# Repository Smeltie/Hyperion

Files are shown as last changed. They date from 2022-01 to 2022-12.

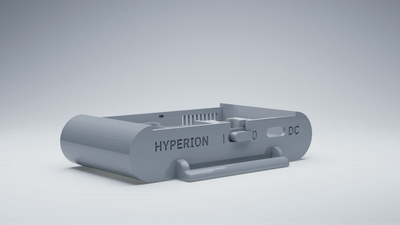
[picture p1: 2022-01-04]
Docs/Case_Lid_Install.gif

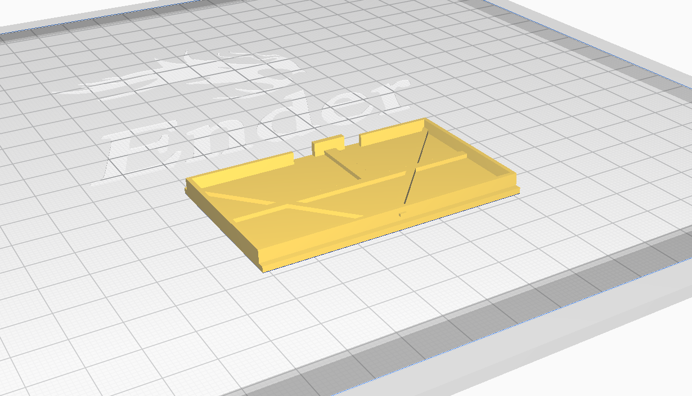
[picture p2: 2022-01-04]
Docs/cura_lid.png

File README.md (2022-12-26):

Imgur <br>

# Hyperion case for DIY SlimeVR!

The Hyperion is one of the smallest and slimmest cases to date for your DIY SlimeVR Trackers. <br>
With its completely tool-less design and tolerances fine tuned specifically for FDM 3D Printers, the Hyperion is both easy to print and assemble! Every part is carefully thought out and clicks together with a satisfying snap, while offering support for various Battery sizes, switches and components.

case

## Index
- [Components](#Components)
- [Compatibility](#Compatibility)
- [Versions](#Versions)
- [Printing](#Printing)
- [Assembly](#Assembly)
- [Links](#Links)
- [Contributors](#Contributors)
- [Contact](#Contact)
- [License (MIT)](#License)

## Components

For the Hyperion you will need the following components:

- [TP4056](https://www.aliexpress.com/item/32649780468.html)
- [Wemos D1 Mini](https://www.aliexpress.com/wholesale?SearchText=D1+mini)
- [40mm straps](https://www.aliexpress.com/item/1005002350231996.html)
- [IMU](https://docs.slimevr.dev/components-guide.html) (*BNO08x chips are currently in a pretty bad shortage*)
    - [MPU6050](https://www.aliexpress.com/wholesale?SearchText=MPU6050)  
    - [BNO08x](https://docs.slimevr.dev/components-guide.html)
- [Switch](https://docs.slimevr.dev/components-guide.html) (*SS22F32 is what the docs suggest, SS12D00G3 is smaller and looks better for this case*)
    - [SS12D00G3](https://www.aliexpress.com/wholesale?SearchText=SS12D00G3)
    - [SS22F32](https://www.aliexpress.com/wholesale?SearchText=SS22F32)
- [Battery](https://docs.slimevr.dev/components-guide.html) (*804040 is what the docs suggest, 503759 is smaller and usually higher capacity*)
    - [804040](https://www.aliexpress.com/wholesale?SearchText=804040)
    - [503759](https://www.aliexpress.com/wholesale?SearchText=503759)

You can also order these parts elsewhere through sites like Amazon with a higher markup which may arrive much faster for a higher cost.

*The straps from the SlimeVR docs are only 25mm wide, while the Hyperion is designed to fit up to 40mm straps for extra stability.*
*Be aware that there are different versions of the TP4056 which are smaller and have less soldering pads, avoid these.*  
*The Micro-USB version of the TP4056 does work but isn't recommended.*

## Compatibility

The Hyperion case offers compatibility for various battery types, for example the 503759 supports any battery that is equal to or smaller than 5x37x59mm.  
Please keep in mind your battery size when planning a build, in this example if you are not using a 503759 or 804040 but your battery is smaller it will still work with this design.  
Be aware that if you use a smaller battery you may have to fill up the space a little bit to prevent the battery from sliding around, while a 503450 would fit just fine.  
  
Hyperion also supports various switch types.  
The case was originally designed to fit the smaller SS12D00G3 switches, but now also supports the SS22F32 (SS12F32 also works).

## Versions

There are a lot of different .STL files included in this project, as the Hyperion supports multiple Battery sizes and separate AUX/extension versions of each case and lid.  
The names of the files indicate what the parts are for and which features they incorporate.  
To clarify some of the terminology, the file name may have a reference to the following:

- *AUX*: This part has an opening for a ribbon/JST cable to an Extension.  
- *BNO08x*: This means the part is meant for BNO08x or MPU 9250/6500 chips
- *BMI160*: This means the part is meant for BMI160 chips
- *503759*: This means the part is meant for batteries that are 5x37x59mm (based on that batteries sizing).
- *SS22F32*: This indicates the part was designed for the switches mentioned in the docs.
- *Slime*: This part has the SlimeVR logo on it, mostly for the lid.
- *Blank*: This part has no print or logo on it, mostly for the lid.

### So which parts do i need?
Of course this is totally dependent on the battery and switch you chose, however you will have to print at least 4 components per tracker, which are:

- Case
- Tray
- Lid
- Switch (*if you opted for the SS12D00G3*)

So for example, you bought a 503739 (or smaller) battery, you would need the following:

- *Case_503759.stl*<br>
- *Tray_503759.stl*<br>
- *Lid_503759.stl*<br>

*BEWARE! if you bought SS22F32 switches, make sure that the part name contains "SS22F32"*

#### If you want to have a tracker that uses an AUX/Extension module
You would need the following:

- *Case_503759_AUX.stl*
- *Lid_503759_AUX.stl*

*The tray is not dependent on the AUX/Extension feature.*

## Printing
It is heavily suggested to print these components on an FDM (Filament based) 3D printer such as the Ender 3 or similar, as all the tolerances have been adjusted to accommodate a wide variety of FDM printers.
Personally I printed my parts on a slightly modified Ender3 V2 using E-Sun PLA+ (gray) with a stock 0.4mm nozzle.

In terms of the printing itself, these parts don't need any support.
Orientation wise the case, tray and switch can be printed as is.
The lid you might want to turn 180 degrees so the flat side is against the bed:

Imgur

#### The Switch
The switch is a little small and harder to print, however it is doable with the right settings:

- *Bed Temperature* - 70c.
- *Initial layer speed* - 10mm/s.
- *Printing speed* - 20mm/s.
- *Infill* - 0%.
- *Layer height* - 0.08mm.
- *Location on the buildplate* - Close to the front or back not in the middle.
- *Build plate adhesion* - Brim.

Imgur

*These settings worked well for me, but your printer may need some slight adjustment. Layer height especially may be challenging for some printers.*
*Take your time and take it slow, I've printed more than a handfull now.*
*Don't print in the middle because on many printers that's a low spot, and this would hinder the adhesion needed to keep this little part stuck down.*

## Assembly

output 

Assembly is rather straight forward however there are some slight things to look out for.
You may have to slightly sand the sides of the tray depending on your printers tolerances, not all printers are created equal. Ideally you will not need to sand anything but it's the easiest solution if any part seems too tight.
It is normal for the tray to snap into place a little bit, it's friction fit.

I suggest soldering things out of the case and using the case/tray as a reference towards wire length, you want to keep your wires rather short like this:

Imgur 

Excess wire length may cause issues with the fit, however there should be more than enough space for wires in the case. You don't have to make them extremely short just keep it manageable.

#### The Switch
After printing the switch the bottom layer of the hole might be a little too tight due to elephant's foot or squish.
In this case you can take a hobby knife or similar and slightly open that first layer up a little bit.

#### The Lid
To install the lid it is best practice to place the lid on the case at an angle with the back side first (vents) so that the notches align. Then lower the front and snap it shut.
To remove the lid again place a fingernail or a pry tool between the lid and the power switch and pry upwards, the lid should snap open.

The lid

#### The Strap
The strap is meant to be run underneath the tracker, otherwise the powerswitch will be obstructed.

## Links
Here are some useful and fun resources:
- [The Docs (SlimeVR Documentation)](https://docs.slimevr.dev/)
- [Github Repository SlimeVR](https://github.com/SlimeVR/)
- [Github Repository Hyperion](https://github.com/Smeltie/Hyperion)
- [Thingiverse Hyperion](https://www.thingiverse.com/thing:5186756)
- [Cults3D Hyperion](https://cults3d.com/en/3d-model/gadget/hyperion-case-for-diy-slimevr)
- [CGTraders Hyperion](https://www.cgtrader.com/free-3d-print-models/hobby-diy/electronics/hyperion-case-for-diy-slimevr)
- [SmeltieVR YouTube](https://www.youtube.com/channel/UC4MEm3i0WxIGPyM8YBV9SSQ)
- [SlimeVR Discord](https://discord.gg/SlimeVR)

## Contributors
I want to put out a sincere thank you to all the people that have helped and tested/measured out various items for this project.  
Thank you: Pjesek, Dinnerbone, Don, Sythe, CalliePepper, Lemming and SuchMeme.

## Contact
If you experience any problems with your Hyperion or have any questions/suggestions?
Feel free to reach out through either Discord I'm [@Smeltie#1999](https://discord.gg/SlimeVR) on the official [SlimeVR Discord server](https://discord.gg/SlimeVR).
You can also shoot me an email: [SmeltieVR@gmail.com](mailto:smeltievr@gmail.com)
If you want to help out with the project or have/want to make a version for a different set of hardware you're more than welcome to send it over or do a merge request!

## License
This project is licensed under the MIT license.

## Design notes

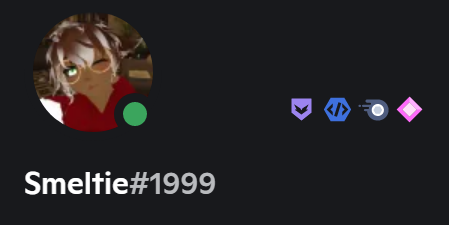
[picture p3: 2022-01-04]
Docs/profile.png

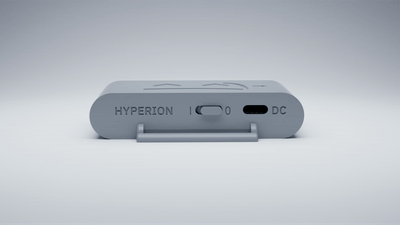
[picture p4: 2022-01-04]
Docs/Case_360.gif

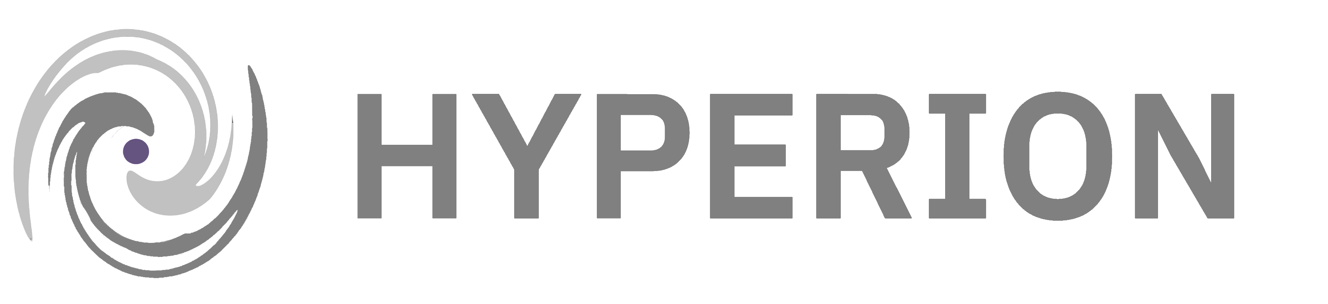
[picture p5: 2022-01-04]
Docs/HYPERION.png

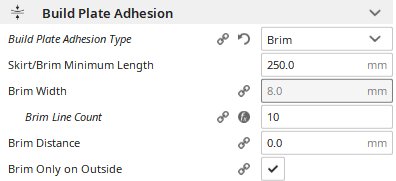
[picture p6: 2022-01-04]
Docs/cura_brim.png

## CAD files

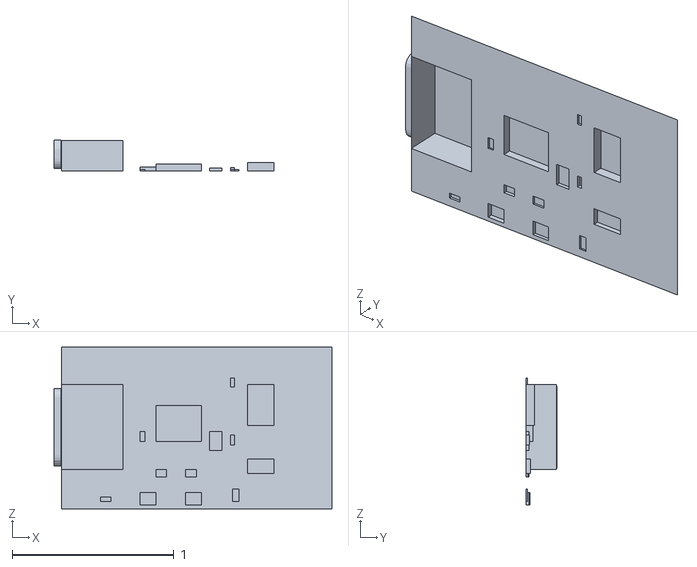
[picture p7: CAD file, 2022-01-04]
3D Models/tp4056.obj
1.72 x 0.193 x 1.00

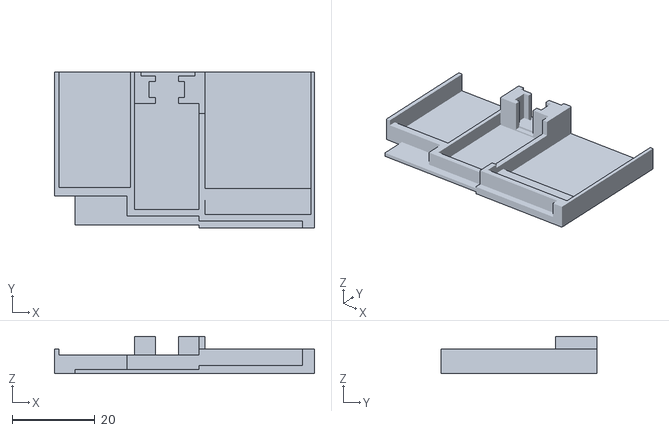
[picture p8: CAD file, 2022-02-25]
STL Files/503759/Tray_503759_BNO08x.stl
62.9 x 37.8 x 9.00

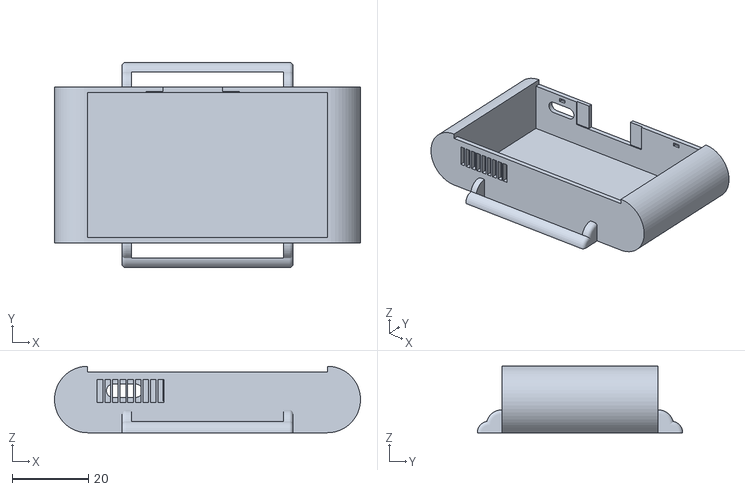
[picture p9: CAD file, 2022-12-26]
STL Files/503759_SS22F32/Case_503759_SS22F32_Switch_Inside.stl
80.5 x 54.0 x 17.5

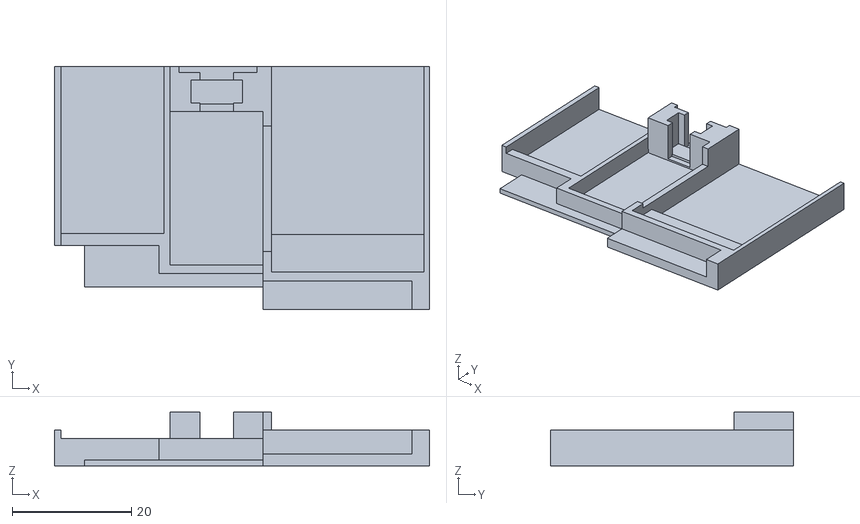
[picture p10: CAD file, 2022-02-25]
STL Files/804040/Tray_804040_BNO08x.stl
62.9 x 40.8 x 9.00

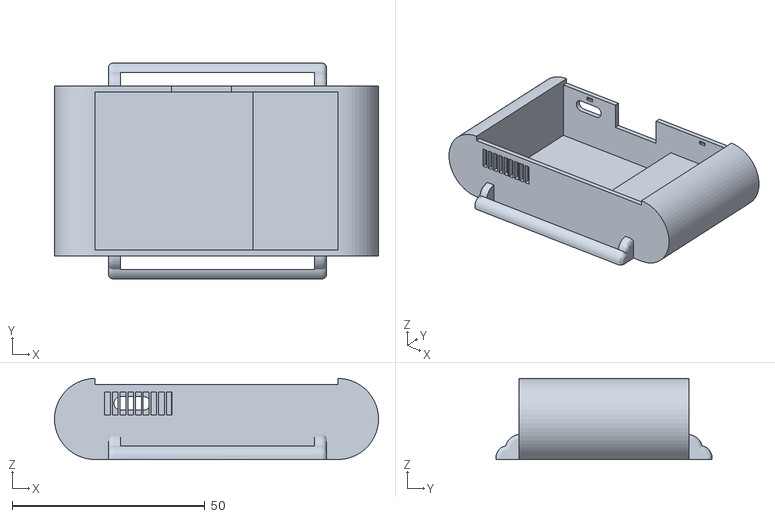
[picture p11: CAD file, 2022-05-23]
STL Files/804040_SS22F32/Case_804040_SS22F32_50mm_Strap.stl
84.0 x 56.0 x 21.0

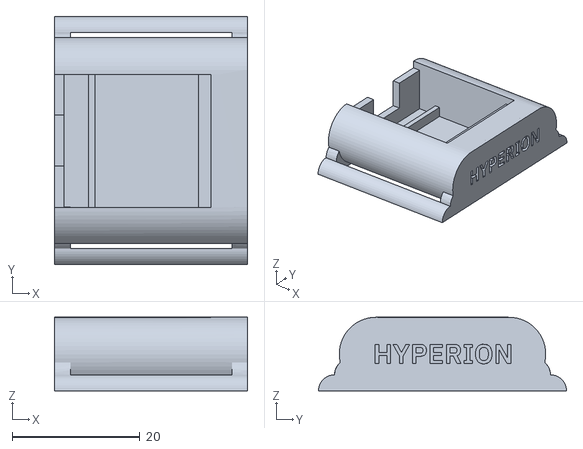
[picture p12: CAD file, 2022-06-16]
STL Files/AUX_Housing_25mm_Strap.stl
30.2 x 38.8 x 11.5

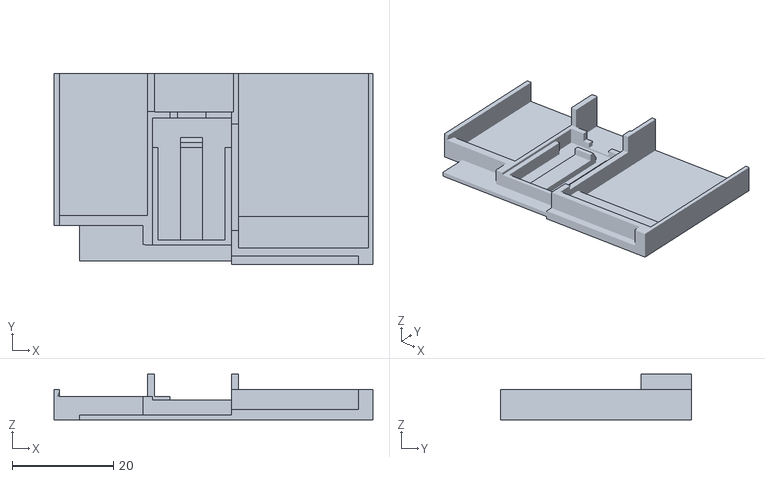
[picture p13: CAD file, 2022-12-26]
Untested/503759_SS22F32/Tray_503759_BMI160_SS22F32.stl
62.9 x 37.8 x 9.00

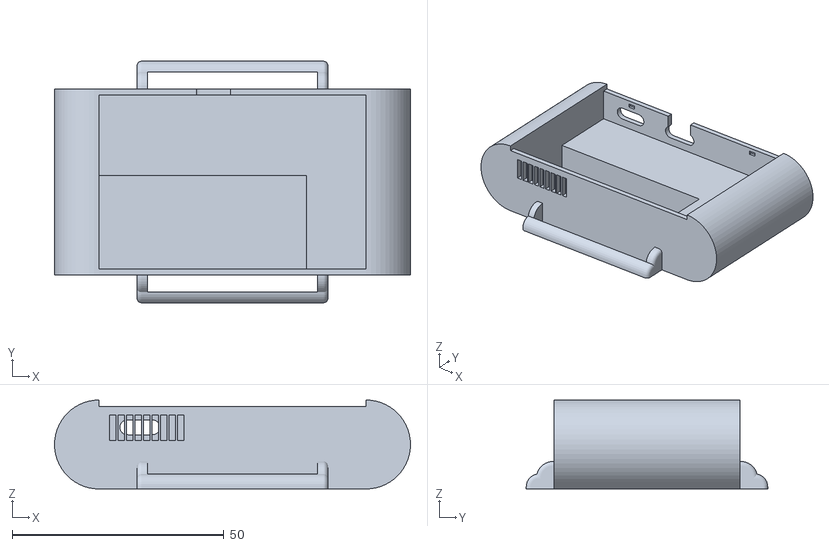
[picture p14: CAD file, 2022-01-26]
Untested/802048/Case_802048.stl
84.0 x 57.0 x 21.0

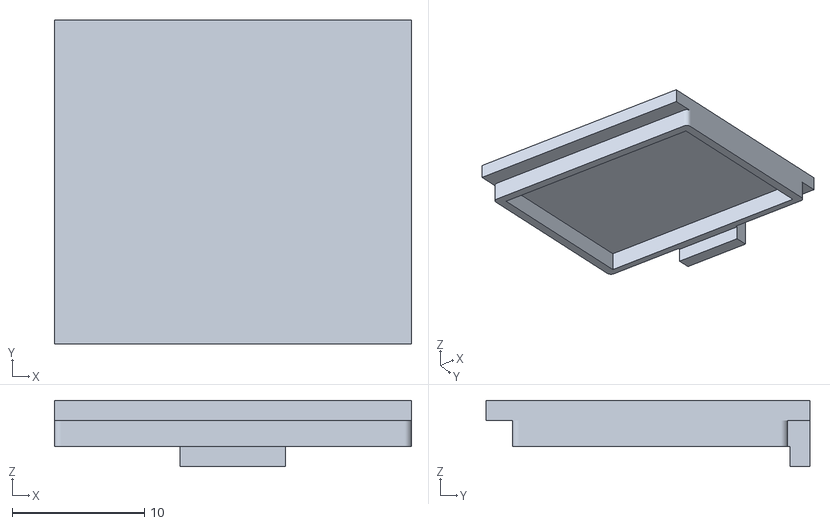
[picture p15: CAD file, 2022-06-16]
Untested/AUX_housing_lid_BNO08x_wide.stl
27.0 x 24.5 x 5.00

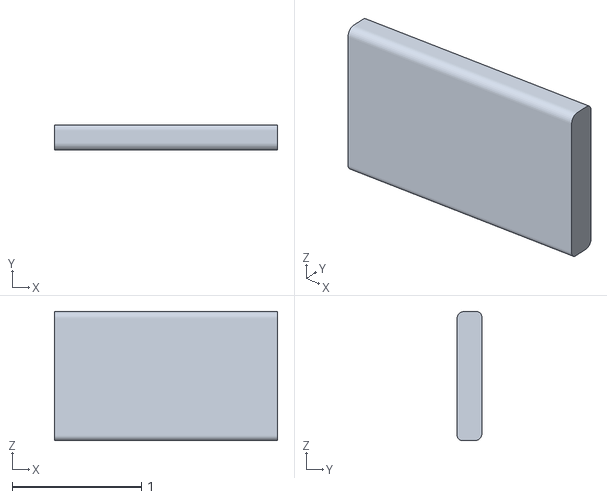
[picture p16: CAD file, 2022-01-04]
3D Models/battery.obj
1.73 x 0.192 x 1.00

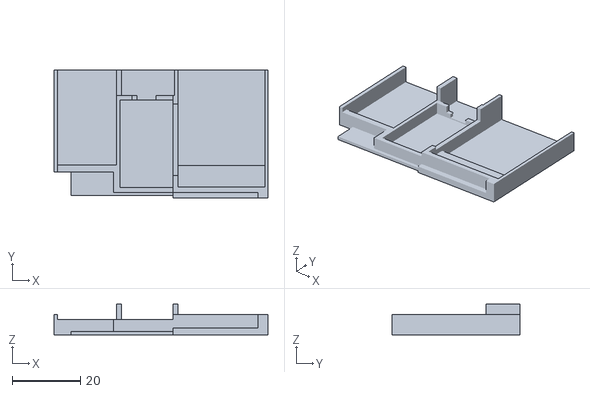
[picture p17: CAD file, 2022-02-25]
STL Files/503759_SS22F32/Tray_503759_BNO08x_SS22F32.stl
62.9 x 37.8 x 9.00

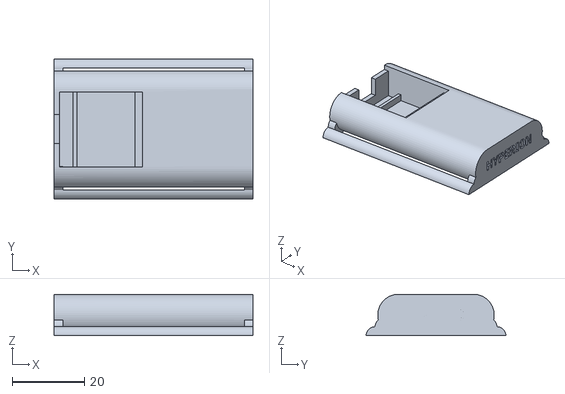
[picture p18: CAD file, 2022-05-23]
STL Files/AUX_Housing_50mm_Strap.stl
55.2 x 38.8 x 11.5

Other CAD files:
Untested/903052/Case_903052.stl
STL Files/503759/Tray_503759.stl
STL Files/804040/Tray_804040.stl
STL Files/804040_SS22F32/Case_804040_SS22F32_AUX_50mm_Strap.stl
Untested/802048/Case_802048_AUX.stl
Untested/903052/Case_903052_SS22F32.stl
3D Models/WemosD1.obj
3D Models/pcb.obj
3D Models/switch.obj
STL Files/503759/Case_503759.stl
STL Files/503759/Case_503759_Aux.stl
STL Files/503759/Lid_503759_AUX_Blank.stl
STL Files/503759/Lid_503759_AUX_Slime.stl
STL Files/503759/Lid_503759_Blank.stl
STL Files/503759/Lid_503759_Slime.stl
STL Files/503759_SS22F32/Case_503759_SS22F32.stl
STL Files/503759_SS22F32/Case_503759_SS22F32_AUX.stl
STL Files/503759_SS22F32/Lid_503759_S22F32_AUX_Blank.stl
STL Files/503759_SS22F32/Lid_503759_S22F32_AUX_Slime.stl
STL Files/503759_SS22F32/Lid_503759_S22F32_Blank.stl
STL Files/503759_SS22F32/Lid_503759_S22F32_Slime.stl
STL Files/503759_SS22F32/Tray_503759_SS22F32.stl
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

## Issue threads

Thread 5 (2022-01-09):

Add support for MPU-9250 & BNO08X

Smeltie, 2022-01-09:
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

Smeltie, 2022-01-10:
I sadly can't get my hands on either version of these boards just yet.

timbit123, 2022-01-17:
I have a BNO and unfortunately my caliper battery is dead but I should be able to confirm it Wednesday otherwise using only the ruler it gave me 26mm x 16mm x 3mm
If you have a test version I should be able to print and test Thursday

Tim

Smeltie, 2022-01-17:
>

I would love to make a version.
I could probably whip one up before then.
Let me see what I can do, it will be in the folder "Untested" when done.

Smeltie, 2022-01-17:
> I have a BNO and unfortunately my caliper battery is dead but I should be able to confirm it Wednesday otherwise using only the ruler I have 26mm x 16mm x 3mm If you have a test version I should be able to print and test Thursday
>
> Tim

Alright so I had some time off tonight and quickly whipped some up.
It gave me some ideas that I will work out later if need be so the files might update but right now this is ready for testing.
let me know how stuff goes and fits and if anything needs additional space!
Files for every version of the tray can be found in the "Untested" folder like described before.

timbit123, 2022-01-18:
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

looks good to me. I'm still waiting for new filament because I tried with a 2yrs old spool that I had and it wrap a bit in the corner but everything fit just fine

Smeltie, 2022-01-18:
> 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
>
> looks good to me. I'm still waiting for new filament because I tried with a 2yrs old spool that I had and it wrap a bit in the corner but everything fit just fine

your BNO seems shorter than the reported measurements but if it fits snugly and doesn't just fall out when moved around and jostled it should be fine.

timbit123, 2022-01-18:
oh you are right I almost have a millimetre of space on the top that I didn't see...
it didn't move because the other side is perfect and was holding it

timbit123, 2022-02-12:
I was assembling the slimevr and found out by surprise the aux housing doesn't work with BNO ether. would it be possible to make a version? Thank you

Smeltie, 2022-02-22:
Hey sorry for the late update, I actually have a set of BNO's inbound expected this very week.
The measurements seem a little off from the sketches provided above.
I'm waiting for mine to come in so I can fine tune the measurements because everything is too loose at the moment.

Got a little busy with life in the meantime.

Smeltie, 2022-02-24:
Alright @timbit123 I've received my BNOs and have since edited the STL files.
They now all fit like a glove and should be good to go.
I've updated the files in the Untested section for now.

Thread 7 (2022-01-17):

Small geometry issue with Case_804040_SS22F32.stl

timbit123, 2022-01-17:
There is a small issue with the model and I could confirm in github stl viewer too

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

you added a rectangle for the smaller battery but between that square and the wall, there is a hidden geometry with two holes that confuse a bit cura

Thanks,
Tim

Smeltie, 2022-01-17:
I looked into it and yeah! there was in fact a small gap on all of the models.
Gap has since been filled and fixed.
Thank you for noticing and reporting this issue!

timbit123, 2022-01-17:
I'm sorry but the issue still there
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

Smeltie, 2022-01-17:
> I'm sorry but the issue still there 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

Ah we weren't talking about the same gap, there were actually 2.
Found it and should be fixed please let me know!

Smeltie, 2022-01-17:
there appears to be another but after double checking in fusion and cura it can't be found anymore.
So i think it's something with the Github Viewer since the faces don't appear to exist anywhere else in particular.

Closed 2022-01-17.

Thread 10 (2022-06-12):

Lid does not fit on the 25mm strap aux case

sevenpoundowl, 2022-06-12:
There is a lip present on the lid that has nowhere to go on the 25mm aux case.

Smeltie, 2022-06-16:
Hey @sevenpoundowl sorry to hear that, I myself didn't make the 25mm aux case so I don't currently have the CAD files for it.
But I think @Lemmingski should have those files still (hopefully)

Lemmingski, 2022-06-16:
I'm looking for it now.  The laptop it was on has been formatted at some
point, but I moved all my files onto another drive first.  So far I've only
found the .STL file.

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

Smeltie, 2022-06-16:
No the new lid has a lip to make sure it doesn't cave in. @Lemmingski

Lemmingski, 2022-06-16:
Gotcha.  Well I have a mission now.  I'll grab the new 50mm version and
adjust accordingly.

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

Smeltie, 2022-06-16:
file has been updated

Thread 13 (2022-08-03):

503759_ss22f32 lids

ArconusNocturn, 2022-08-03:
None of the lid files will open in Cura, it says they are corrupted or don't contain models. All other files in the directory work normally.

Smeltie, 2022-08-11:
I can't replicate the issue myself.
It seems the file might have been corrupted upon download.
Maybe try downloading the files from either: printables, cults3D or thingiverse.
I am unable to replicate this issue myself.

Closed 2022-08-11.

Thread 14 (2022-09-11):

Improvement: Air vent difficult to print beautifully

dingyifei, 2022-09-11:
The air vent with the shape of IIII is hard to print on most FDM machines because the frequent retraction and low volume&movement extrusion increases the chance of clogging.

A way to make better air vents is to design them as wavy lines (small triangles) in and out of the case wall, from the top side it would look like

```
<
 >
<
 >
```

So holes are open on Z instead of X/Y, making these lines printable as continuous lines

An example 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

Smeltie, 2022-09-11:
Thank you for the suggestion.
Hyperion is currently not a project that I’m actively working on.
And it appears most people seem to be able to print the little spokes just fine (since they are dialed in for a .4 nozzle specifically.
That’s not to say this is a bad idea or shouldn’t be added.
The project is open source and MIT licensed so feel free to add this as a forked version of sorts.

Closed 2022-09-11.

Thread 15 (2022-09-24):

Support for BNI160?

hbjydev, 2022-09-24:
Hey there,

Love the design of this case, it's the one I'd like to go with if I can have Thingiverse print it for me lol

Just wanted to know if the sizings would be compatible with a BNI160? That's the accelerometer I've got on order :)

Thanks!

Smeltie, 2022-09-24:
Sadly the BMI does not fit but there should be a remix on thingiverse soon that accomodates it, saw someone working on it.

hbjydev, 2022-09-24:
Oh, awesome. Thanks for the stupidly quick reply, I hadn't even closed the tab yet lol

Smeltie, 2022-09-24:
I just so happened to look at that exact moment :)

Closed 2022-09-24.

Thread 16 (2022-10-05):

make an opening for the micro usb of the d1

CosmicSnow, 2022-10-05:
it would be great to have a opening for the micro usb of the micro controller,
it would let updates without the need to open lid

Smeltie, 2022-10-06:
I purposely left this hole out because:
- the hole would need to be significantly bigger than the actual port because it’s recessed into the case.
- It would massively reduce structural integrity
- The main tray can be removed within a few seconds
- You only have to flash the trackers once by cable, after that you can reflash OTA (over the air) aka wirelessly afterwards.

So after considering all these things I decided it wasn’t worth the reduced strenght and massive hole at the front.
But I know several people have made edits of the case with said hole.
Hopefully this answered your suggestion/question.

Closed 2022-10-06.

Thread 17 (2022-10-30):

903052 Case - Battery Slot Expansion

MellowMarble, 2022-10-30:
I just got some of the [Amazon 903052s](https://www.amazon.com/dp/B088YKPZ9D/) linked from the SlimeVR [Components Guide](https://docs.slimevr.dev/diy/components-guide.html#components-guide) and most of them are measuring about 58-59mm long. Expanding the battery compartment to 60 mm gave them a good fit. I didn't file a PR since I'm not sure if you wanted these loose or friction tight. At 60mm..half fall out when turned upside down and the others come out with the slightest tap.

After Expanding the slot by 5mm to reach 60mm total:
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

vsmatthews, 2022-12-06:
hi! how did you print the hole thing? i also have de 903052. My switch is SS22F32 and the chip mpu6050.

Smeltie, 2022-12-14:
seems more like the batteries off of amazon are mislabeled.
However since I have included all the files you should be able to edit them fairly easily with 1 or 2 extrude actions.
Apologies for the delayed reaction.

Closed 2022-12-14.

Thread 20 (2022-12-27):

BMI160 with SS12D00G3 and 503759

LunarstarPony, 2022-12-27:
So I see on the official Doc that BMI160 is the current go-to IMU for DIY Slime So I wonder is there a tray for this setup rn? I see the one for 503759 with SS22F32 but not SS12D00G3.

Smeltie, 2022-12-27:
As described in the documentation there is currently an experimental tray for the bmi 160.
It’s in the untested folder.
But it’s only for specific components.
The fusion files are included so you can easily edit the original in a few clicks as well.

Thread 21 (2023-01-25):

Tray_503759_BNO08x.stl

Originalas, 2023-01-25:
MPU-9250 is a hair too tall to fit the 503759_BNO08x tray. The hole needs to be around 0.5mm taller.

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

Smeltie, 2023-01-25:
That’s odd, they should be the same size as the BNO08X modules which are confirmed to fit.
This might be a different MPU9250 breakout manufacturer that uses different sizing/tolerances?

I am personally running these for my BNOs.
I’ve included the CAD files in this repo, you could fairly easily knock the wall back a hair to get your modules to fit.
Hope this helps!

Originalas, 2023-01-25:
It's a very tight fit. :) It worked after little cleaning with a dremel.
I guess, print has a little bit rounded corners and I smoothed the end of the board too. Maybe I will scale other prints to 102% size or something like that.

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

Closed 2023-01-25.

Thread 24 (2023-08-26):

Duplicate filename inside repository

caboose89, 2023-08-26:
Inside `STL Files` there are two files called `AUX_Housing_25mm_strap.stl`
One has an uppercase S on the word Strap. This is fine for *nix systems where the OS supports case sensitive paths, but this will not work on Windows systems.
The uppercase file seems to be newer ( Jan5 '22 vs Jun 16 '22), and has an additional notch for the lid not present in the older version.

I would recommend either removing or renaming the older file.

Thanks for all the work on the project! Got mine printing in resin now to see if resin prints are resilient enough.

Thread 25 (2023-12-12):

No AUX case for BNO085 (SlimeVR) chips

ButterMeWaffle, 2023-12-12:
The AUX case is too small for the BNO085 (SlimeVR) chips. Any chance someone has this file? I can try to edit the existing design myself but I dont have any relevant experience for the job (new to 3d printing in general).

ButterMeWaffle, 2023-12-12:
I decided to look in the untested folder and found it! im going to leave this up and report back on how well the chip fits.

Speaking of how well the chip fits, I cant seem to get the BNO085 (SlimeVR) chip to fit into the tray without cutting out most of the walls around the slot for it. I dont believe its an issue with printer settings but as I said im new to this so its possible. Just seems a little too off to be my settings since everything else seems to be accurate

ButterMeWaffle, 2023-12-12:
so the file I found (https://github.com/Smeltie/Hyperion/blob/main/Untested/AUX_Housing_BNO08x.stl) is close but like the BNO08x tray its just a little too tight. I can probably cut it down like I have to do with the tray and make it work. I might try to get into the design files and modify it to fit but my confidence is fairly low

ItsVRK, 2023-12-14:
> so the file I found (https://github.com/Smeltie/Hyperion/blob/main/Untested/AUX_Housing_BNO08x.stl) is close but like the BNO08x tray its just a little too tight. I can probably cut it down like I have to do with the tray and make it work. I might try to get into the design files and modify it to fit but my confidence is fairly low

Can you sand the edges of the BNO08 board to make it fit?

ButterMeWaffle, 2023-12-14:
> > so the file I found (https://github.com/Smeltie/Hyperion/blob/main/Untested/AUX_Housing_BNO08x.stl) is close but like the BNO08x tray its just a little too tight. I can probably cut it down like I have to do with the tray and make it work. I might try to get into the design files and modify it to fit but my confidence is fairly low
>
> Can you sand the edges of the BNO08 board to make it fit?

Its a big enough difference that I need to cut away about half of the wall. I modified the files to make it fit, its a bit off but it works.

ItsVRK, 2023-12-15:
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

Have you posted the STL's anywhere? I've just printed the ones from Untested folder, but waiting on the BNO08's to arrive from slimevr before I can build

ButterMeWaffle, 2023-12-15:
@ItsVRK no I havent, they are a bit too flawed for me to want to share them. I reached out to the creator on discord to see if he is willing to adjust them in a less jank way. I am going to move forward with my flawed version but id like to get the files fixed to avoid this situation in the future

ItsVRK, 2023-12-21:
@ButterMeWaffle My BNO085's arrived from SlimeVR today and fit in the versions of https://github.com/Smeltie/Hyperion/blob/main/Untested/AUX_Housing_BNO08x.stl that I printed fine, perhaps you need to calibrate your printer?

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

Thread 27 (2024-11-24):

No CAD Files for AUX

Unavailable-is-Username, 2024-11-24:
I've been making a lot of edits to all the components due to the need for it to fit parts I could get locally, however, there is no step file containing anything for the AUX trackers. IT's made worse as my BNO085 IMUs slide around in the BNO AUX Tracker, Also the JST port doesn't fit in the hole. It would be very helpful if I could have some CAD files of these AUX enclosures, so I can make the edits I need, myself, in Adsk Inventor.

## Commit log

2022-01-04 Initial File Dump
    [Case_503759.stl, Case_503759_Aux.stl, Case_804040.stl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]
2022-01-04 Second file dump
    [AUX_Housing.stl, AUX_Housing_Lid.stl]
2022-01-05 updated trays
    [Tray_503759.stl, Tray_804040.stl]
2022-01-05 Fixed mysterious gap in the Trays
    [Tray_503759.stl, Tray_804040.stl]
2022-01-07 Better wiring picture
2022-01-10 Added expirimental new switch version (untested)
    [Case_503759_SS22F32.stl, Case_503759_SS22F32_AUX.stl, Tray_503759_SS22F32.stl]
2022-01-10 shifted the switch .45mm
    [Case_503759_SS22F32.stl, Case_503759_SS22F32_AUX.stl, Tray_503759_SS22F32.stl]
2022-01-10 Added untested switch for 804040 and restructure of folders
    [Case_503759_SS22F32.stl, Case_503759_SS22F32_AUX.stl, Case_804040_SS22F32.stl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]
2022-01-10 added 1 lid correction really quickly
    [Lid_503759_S22F32.stl]
2022-01-11 fixed lid lip
    [Lid_503759_S22F32_Blank.stl, Lid_503759_S22F32_Slime.stl]
2022-01-13 Added all files for SS22F32 switches
    [Lid_503759_S22F32_AUX_Blank.stl, Lid_503759_S22F32_AUX_Slime.stl, Lid_503759_S22F32_Blank.stl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]
2022-01-13 updated README to include SS22F32 preparing files for move into main.
    [Case_804040_SS22F32.stl, Case_804040_SS22F32_AUX.stl]
2022-01-13 Merged SS22F32 files into main parts are tested by 2 users.
    [Case_503759_SS22F32.stl, Case_503759_SS22F32_AUX.stl, Case_804040_SS22F32.stl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]
2022-01-17 added expirimental BNO support
    [Tray_503759_BNO08x.stl, Tray_503759_BNO08x_SS22F32.stl, Tray_804040_BNO08x.stl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]
2022-01-17 Added expirimental version 903052, lid+tray are the same as 804040
    [Case_903052.stl, Case_903052_AUX.stl, Case_903052_SS22F32.stl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]
2022-01-17 updated STL files with gap fix
    [Case_503759.stl, Case_503759_Aux.stl, Case_503759_SS22F32.stl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]
2022-01-17 another gap fixed
    [Case_804040.stl, Case_804040_AUX.stl, Case_804040_SS22F32.stl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]
2022-01-18 meshes checked for more issues and these have all been patched now!
    [Case_503759.stl, Case_503759_Aux.stl, Case_503759_SS22F32.stl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]
2022-01-26 added 802048 to Untested
    [Case_802048.stl, Case_802048_AUX.stl, Case_802048_SS22F32.stl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]
2022-02-16 fixed tray
    [Tray_503759.stl, Tray_503759_BNO08x.stl, Tray_503759_BNO08x_SS22F32.stl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]
2022-02-24 updated BNO support
    [Tray_503759_BNO08x.stl, Tray_503759_BNO08x_SS22F32.stl, Tray_804040_BNO08x.stl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]
2022-02-25 Updated BNO trays and AUX housings
    [AUX_Housing.stl, AUX_Housing_BNO08x.stl, AUX_Housing_Lid.stl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]
2022-02-25 Moved BNO trays into the main
    [Tray_503759_BNO08x.stl, Tray_503759_BNO08x_SS22F32.stl, Tray_804040_BNO08x.stl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]
2022-06-15 Added files for wide case
    Added new AUX case design for the larger MPU9250 and BNO08x boards, accommodations for both 25mm and 40mm straps as well as larger loops to more closely match the main case, allowing for more compati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
    [AUX_housing_BNO08x_25mm_wide.stl, AUX_housing_BNO08x_40mm_wide.stl, AUX_housing_lid_BNO08x_wide.stl]
2022-06-16 New version of 25mm AUX with lip for newer lid
    [AUX_Housing_25mm_Strap.stl]
2022-12-17 Add Case_503759_SS22F32_Switch_Inside.stl
    [Case_503759_SS22F32_Switch_Inside.stl]
2022-12-17 Add Tray_503759_BMI160_SS22F32.stl
    [Tray_503759_BMI160_SS22F32.stl]
